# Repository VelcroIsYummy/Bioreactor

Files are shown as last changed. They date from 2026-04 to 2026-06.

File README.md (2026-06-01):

# Bioreactor?
This project is a expandable and usable bioreactor designed to allow **you** to grow bacteria, fungi, anything you can grow in a conventional bioreactor! Essencially this is a sterile volume, with ports or holes for instumentation (thermocouples, pH sensors, ect.) with software for controlling and managing the systems within. This bioreactor is unique (compared to other options at this price) by being very open and easy to build (some are open source, however they typically don't have great instructions on how to build your own.) Being very easily expandable, for example, extra slots are included if you want more motors, and it's easy to just add them (all design files are included.) And finally, being much larger than most other options (500mL.)

# Why?
Decentralized science is one of the most pivotal steps toward our future, wether it's finding a cure for an obscure disease (very unlikely), or providing resources to those who need it, decentralized science is the solution. Our project enables this, helping fuel a better future for us all. Perhaps one day someone will use it for something like producing insulin in areas that have limited outside access. The reason why I personally needed this is simple: I have a science fair that involves the growth of bacteria.

# Features
This bioreactor is a pretty full-fledged bioreaction system, it can grow almost any organism (that you could with a insustrial bioreactor), has dosing systems, optical density measurments, temprature control and a online, accessible UI. The only thing that this bioreactor can't handle is significant pressure differentials, as it's just not meant for that.

## BOM
| Name | Purpose | Quantity | Total Cost (USD) | Link | Distributor |
| --- | --- | --- | --- | --- | --- |
| Perfboard | It is used to connect everything together. | 1 | 8.00 | https://www.amazon.ca/Protoboard-Solderable-Breadboard-Electronics-Projects/dp/B0B9F2DNXD/ | Amazon |
| Schottky Diodes (Pack of 10) | The Schottky diodes are so that the MOSFET doesn't burn out due to back EMF. | 1 | 3.41 | https://www.aliexpress.com/item/1005007566611868.html | Aliexpress  |
| 500mL Media Storage Bottle | It shall be used to contain the media in which the biological processes are happening. | 1 | 30.00 | https://stonylab.com/products/250ml-wide-mouth-media-storage-bottle?variant=47202194620674 | StonyLab |
| CoPA filament | It is to print some parts that will either be exposed to warm temperatures and that will be contacting the media (for sterilization reasons.) And yes you only need a few hundred grams but this is the smallest size I could find. | 1 | 43.70 | https://www.amazon.ca/gp/product/B09MTC51RH/ | Amazon |
| 20x20x6mm fan | This fan is used to pass air through the PTFE filter, a high airflow isn't required for my perposes but you may need it. | 2 | 3.72 | https://www.aliexpress.com/item/1005009082132202.html | Aliexpress  |
| S8050 | It is used to switch the MOSFET on and off, | 1, Pack of 20 | 1.40 | https://www.aliexpress.com/item/1005008583538092.html | Aliexpress  |
| IRFZ44N | The MOSFET is used both for motor control, and for the control of the heater. | 1, Pack of 10 | 2.42 | https://www.aliexpress.com/item/1005007580466441.html | Aliexpress  |
| Thermal Paste | The thermal paste is so that the heater pad and the media container can have proper conduction, as otherwise heat transfer would be poor. | 1 | 8.74 | https://www.amazon.ca/Thermal-Grizzly-Kryonaut-Grease-Paste/dp/B011F7W3LU/ | Amazon |
| MAX6675 | It is so that I may use the thermocouple in coordination with the Arduino. | 1 | 6.50 | https://www.amazon.ca/MAX6675-Thermocouple-Temperature-Sensor-Module/dp/B07YC25RFW/ | Amazon |
| Type K thermometer | It is used for PID control and data collection. | 1 | 8.74 | https://www.amazon.ca/MECCANIXITY-Surface-Thermocouple-Handheld-Temperature/dp/B0CCSKDCW3/ | Amazon |
| Geared Motor | It is used in order to stir the media, allowing equal dispersion of materials and organisms. | 1 | 15.60 | https://www.aliexpress.com/item/1005010720335071.html | Aliexpress  |
| Silicone Heating Pad 12V/40W | It is used for heating and maintaining the temperature of the media. | 1 | 10.00 | https://www.aliexpress.com/item/1005005338245057.html | Aliexpress  |
| 12V/15A Power Supply | I shall use this PSU for powering the Bioreactor's systems. | 1 | 19.67 | https://www.aliexpress.com/item/1005011601037869.html | Aliexpress  |
| Arduino R4 WiFi | The Arduino WiFi is used for the control of biological processes (pH control, temperature control, ect.) and for communications through MQTT and a python API. | 1 | 27.50 | https://store-usa.arduino.cc/collections/uno/products/uno-r4-wifi | Arduino |
| 5mm LED | The light emitting diodes are used to pass light through ~1cm of media and calculate the OD600. | 1, Pack of 100 (smallest I could find) | 6.50 | https://www.amazon.ca/gp/product/B09BPQWV2W/ | Amazon |
| Adafruit TSL2591 | Used to measure the intensity of light on the other side of the media, thus allowing the calculation of OD600. | 1 | 6.95 | https://www.digikey.ca/fr/products/detail/adafruit-industries-llc/1980/4990786 | DigiKey |
| 25mm PTFE Filters, Hydrophillic | Used to prevent contaminants like bacteria and water from getting into the reactor vessel | 1, Pack of 50 (minimum size) | 12.90 | https://www.amazon.ca/Deschem-Hydrophilized-Membrane-Filter-Polytetrafluoroethylene/dp/B07TC2RQYN | Amazon |
| 3m 18mm OD 14mm ID Sillicone Tube | Used to move air through a filter into the bioreactor, allowing the growth of aerobic bacteria. | 1 | 6.50 | https://amazon.ca/silicone-flexible-rubber-tubing-transparent/dp/b08hjgwkx3/?th=1 | Amazon |
| 5.4mm Luer fittings female | Used to allow a sterile connection that can move fluids, very useful for doising and extraction. | 1 | 4.90 | https://www.amazon.ca/Hynec-Polypropylene-Female-Luer-Connector/dp/B0F1ZX2S71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 | Amazon |
| Luer tube | Used to move fluids in a sterile way between the reagent tubes and the vessel. | 4 | 7.20 | https://www.aliexpress.com/item/1005005528071293.html | Aliexpress |

(The reason the prices are in USD is because origonally this project was for Stasis, however I migrated before I really started doing most of the coding and design.) Another note, I'm not requesting funding for all of these since I have a lot of the parts.

# Usage
The usage of this bioreactor is pretty simple, after assembly, connect it to the internet (you can put in your WiFi password by just adding it to the "secrets.h" file.) After this, just turn on the PSU, and connect to it on the internet. The process by which you connect everything together, and set up the web UI is detailed in the instructions.

# Requirements/Libraries
For this project to work you will need to download the following libraries:

## Arduino

- PID (https://github.com/br3ttb/Arduino-PID-Library/tree/master)
- MAX6675 (https://github.com/RobTillaart/MAX6675)
- functional (included with Arduino IDE)
- WiFiS3 (included with Arduino IDE)
- ArduinoMqttClient (https://github.com/arduino-libraries/ArduinoMqttClient)
- RTC (https://github.com/cvmanjoo/RTC)
- Adafruit_Sensor (https://github.com/adafruit/adafruit_sensor)
- Adafruit_TSL2591 (https://github.com/adafruit/Adafruit_TSL2591_Library/)
- HttpClient (https://github.com/amcewen/HttpClient)
- Wire (Included with Arduino IDE)

## Python
- FastAPI (https://github.com/fastapi/fastapi)

# Disclamer
While I made most of this project myself, I obviously didn't create certain things like the libraries. I also used resources like StackOverflow for this. Another thing to note, I did not create the original models for the ported caps and the headplate, I simply _**CANNOT**_ make threads for some reason.

## Refrences I Used
- Python Docs
- Javascript MDN Docs
- ElectroNoobs (https://electronoobs.com/)
- Examples (The files that are included with most libraries, showing how to use them)
- StackOverflow
- W3, for learning (I'm still new to this stuff)

# Schematic
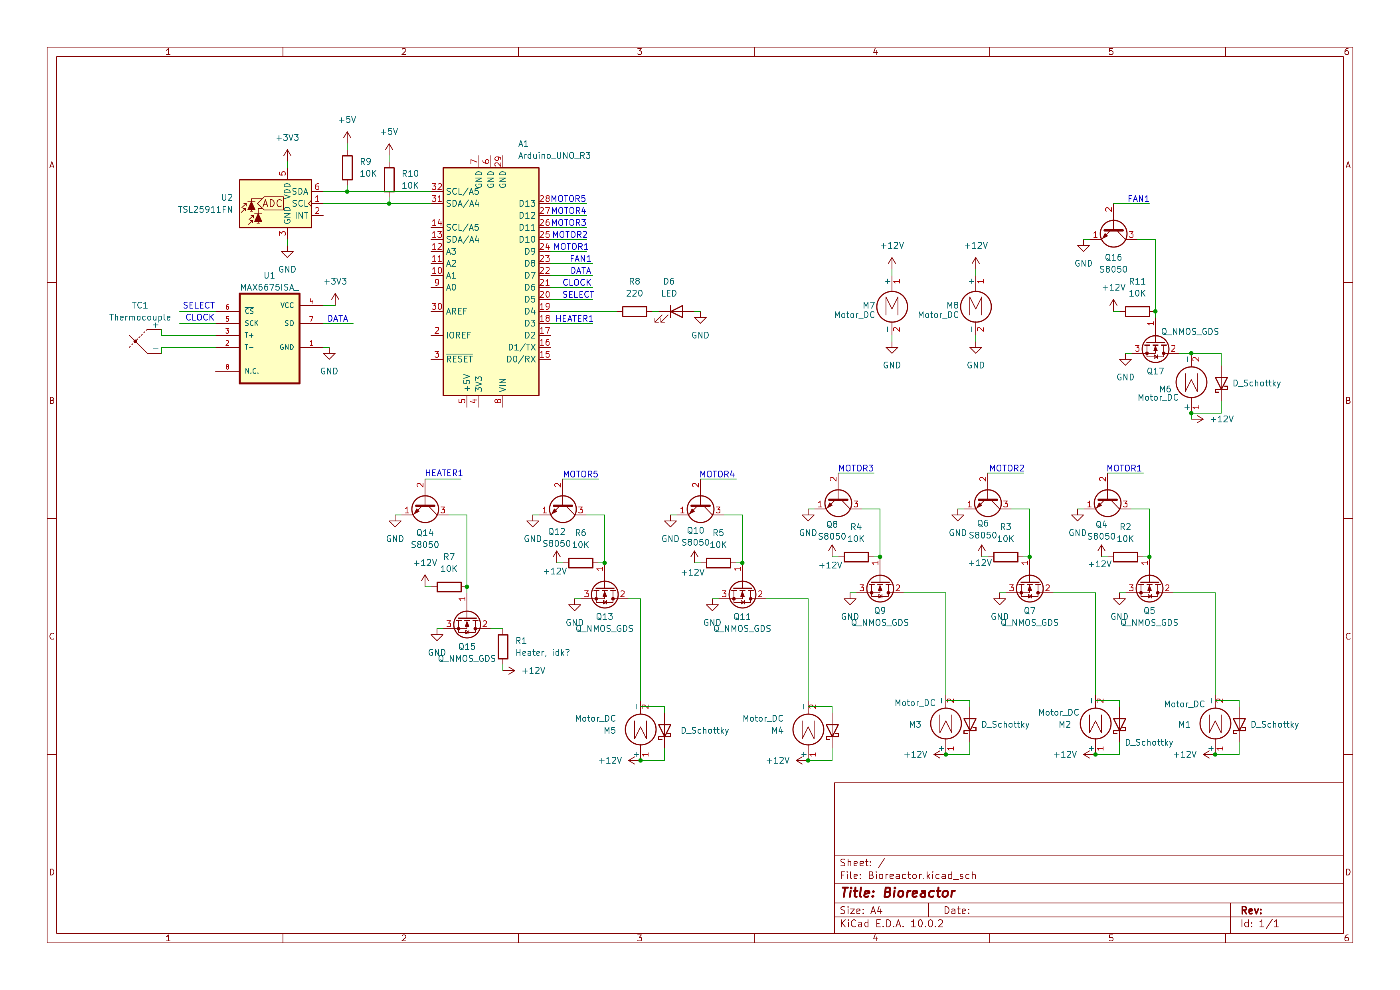
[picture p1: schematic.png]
Schematic


# Zine
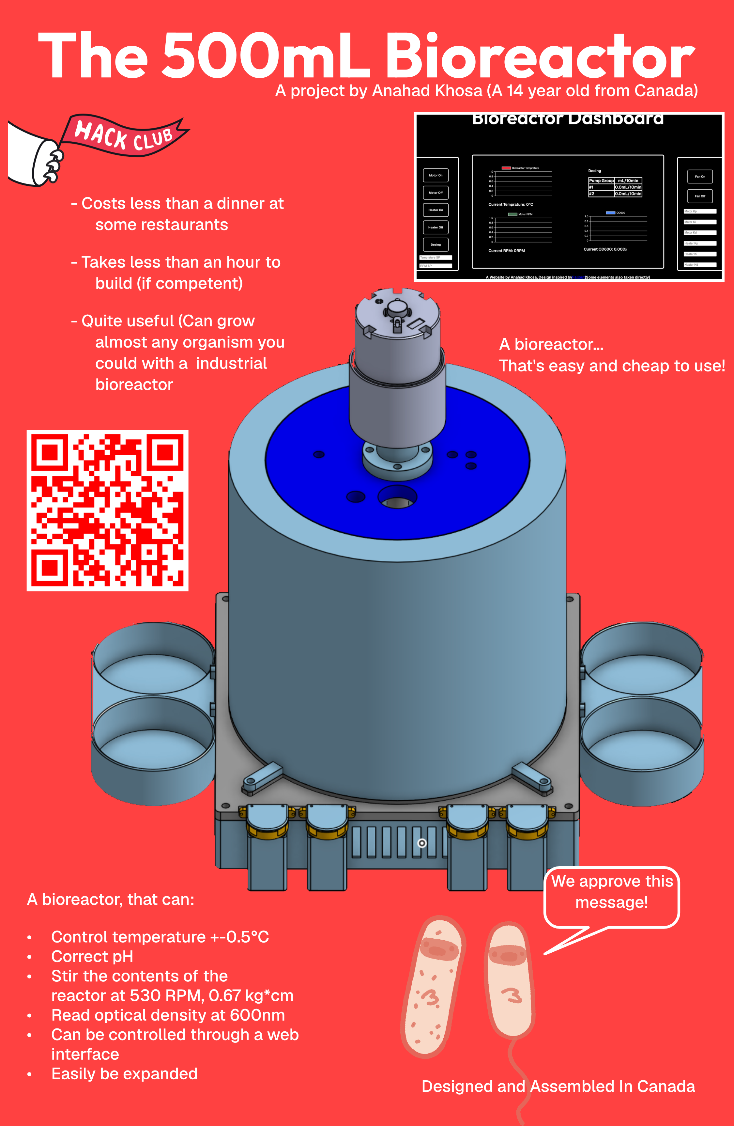
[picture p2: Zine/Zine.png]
Zine


# Onshape Links
Here are the onshape links if you want them
- For the Arduino Enclosure, the motor holder, reagent bottle holder and the assembly of everything put together https://cad.onshape.com/documents/7da2fef4892da00e546072ac/w/9fd6f0965d1d0b5f1b6a90d1/e/e24ce9c144e045758d9770eb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
- For the heater holder, the motor shaft, and motor holder https://cad.onshape.com/documents/63b4c3fef69abd726d6ab222/w/4431f9c62b980bae8326396e/e/164de285b85071f5c7627032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
- Reagent bottle cap with 2 ports https://cad.onshape.com/documents/1eed58fe4840c910f07571ab/w/ff7b350df8e7dc2f2e59ebc7/e/ee4f5e3626b7f9089b5a21a8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
- Headplate, used to mount sensors and the motor https://cad.onshape.com/documents/97e268ccdf9d28071c848c08/w/29b871e1c28c8c8f8ed3ce92/e/f98ecdd4111ee4c6ba3b3adb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

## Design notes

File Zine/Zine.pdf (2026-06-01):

# The 500mL Bioreactor

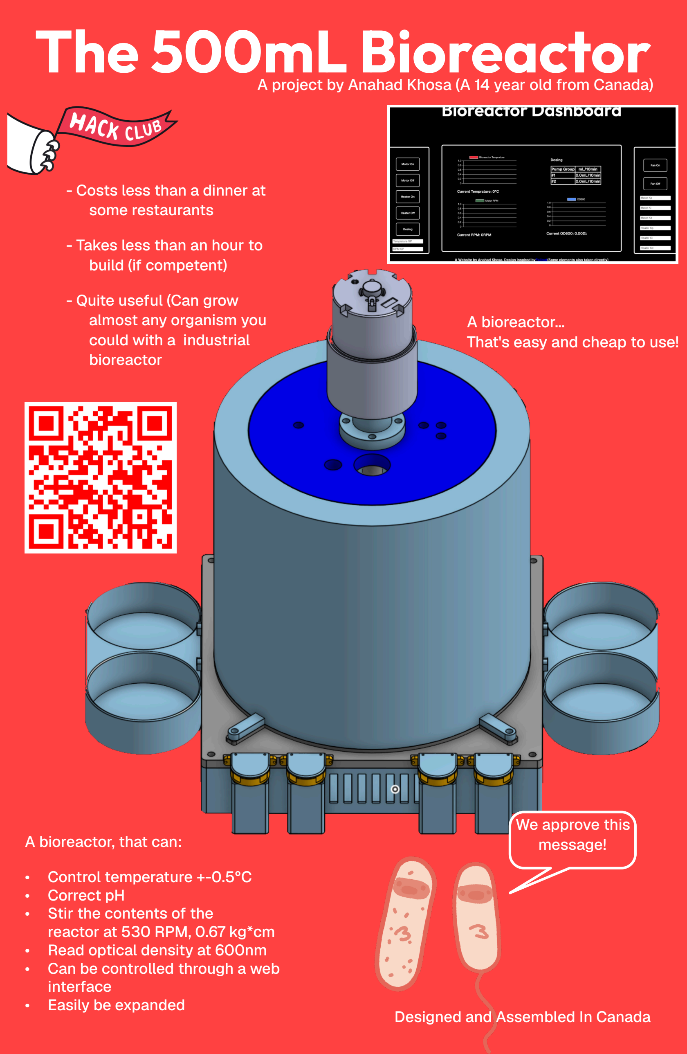
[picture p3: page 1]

A project by Anahad Khosa (A 14 year old from Canada)

A bioreactor...
That's easy and cheap to use!

A bioreactor, that can:

- Control temperature +-0.5°C
- Correct pH
- Stir the contents of the
reactor at 530 RPM, 0.67 kg*cm
- Read optical density at 600nm
- Can be controlled through a web interface
- Easily be expanded
- Costs less than a dinner at some restaurants
- Takes less than an hour to build (if competent)
- Quite useful (Can grow
almost any organism you
could with a industrial
bioreactor

Designed and Assembled In Canada

We approve this
message!

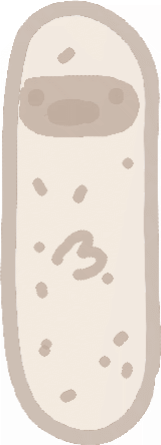
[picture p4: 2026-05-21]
src/Bioreactor GUI/Stew.png

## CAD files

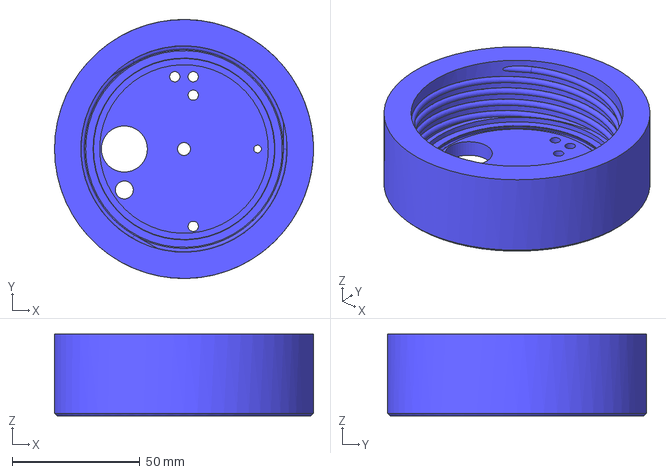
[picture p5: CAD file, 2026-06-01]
CAD/Headplate.step
101.4 x 101.4 x 32.0 mm

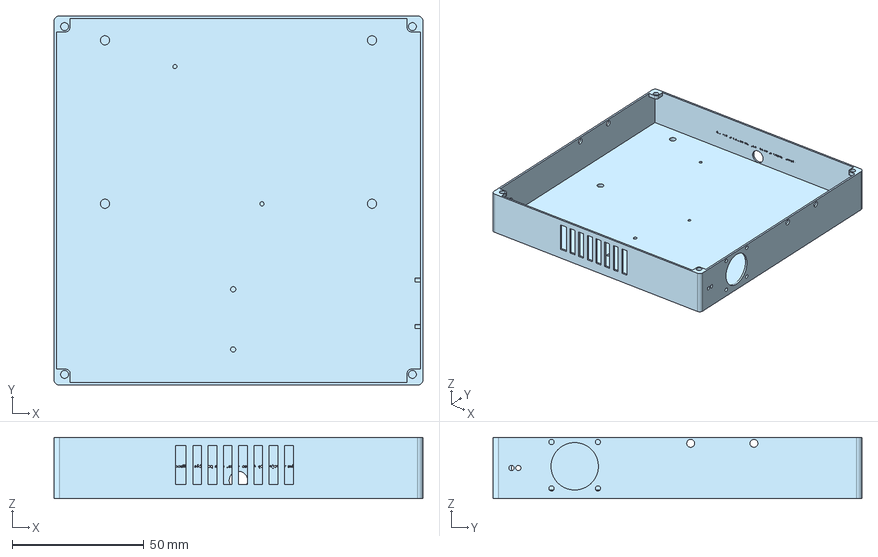
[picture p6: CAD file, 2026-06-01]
CAD/Arduino Enclosure.step
140.0 x 140.0 x 23.3 mm

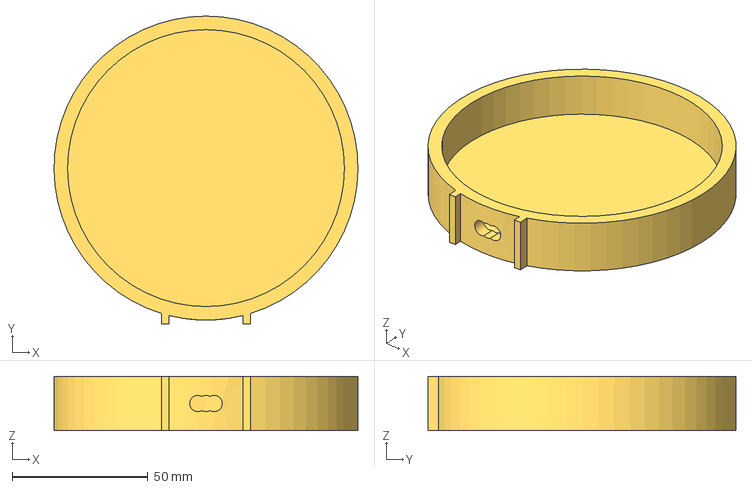
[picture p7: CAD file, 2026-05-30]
CAD/Heater Base.step
112.0 x 113.4 x 20.0 mm

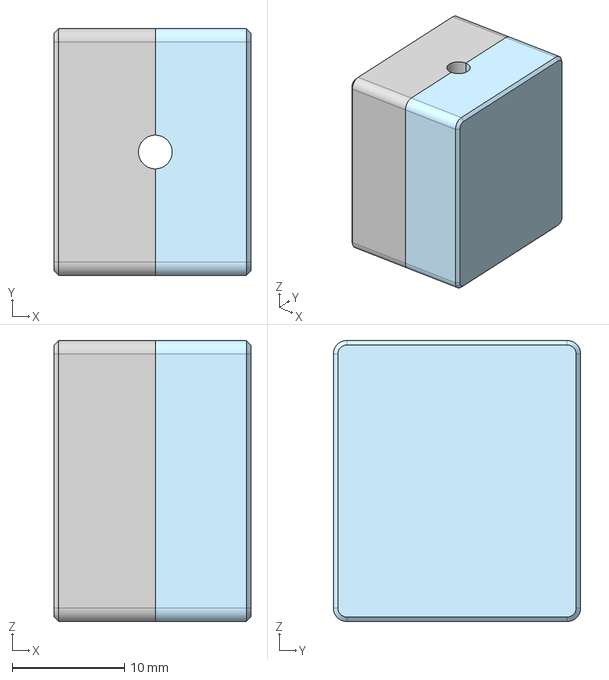
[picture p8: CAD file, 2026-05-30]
CAD/OD600 Module.step
17.5 x 22.0 x 25.0 mm

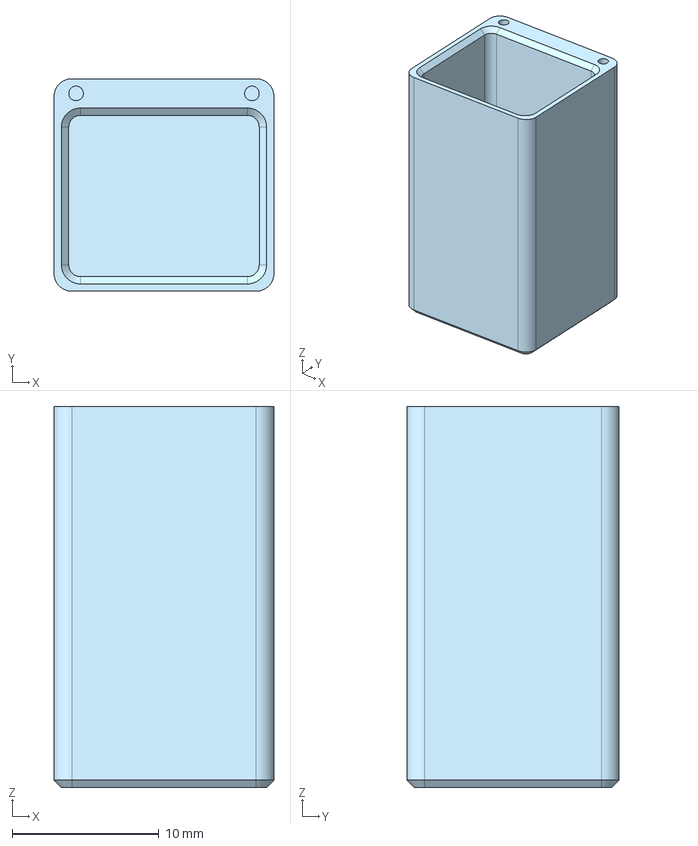
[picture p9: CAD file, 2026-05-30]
CAD/Dosing Motor Holder.step
15.0 x 14.5 x 26.0 mm

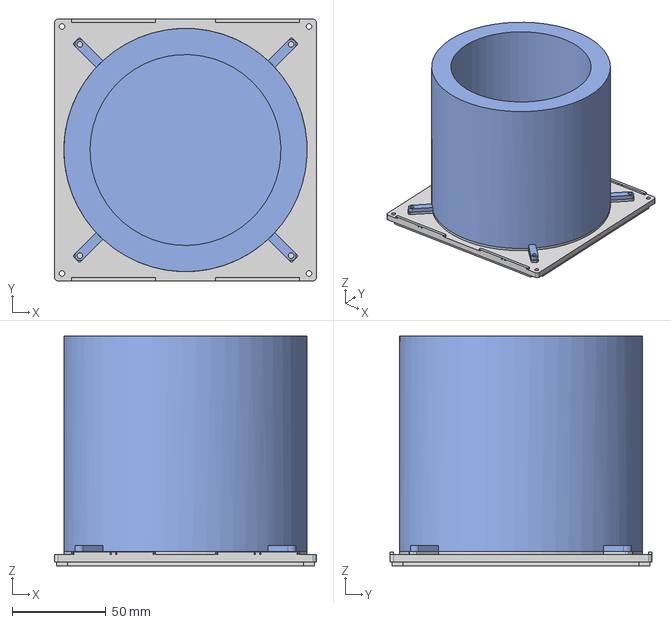
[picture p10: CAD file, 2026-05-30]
CAD/Arduino Enclosure Lid.step
140.0 x 140.0 x 122.8 mm

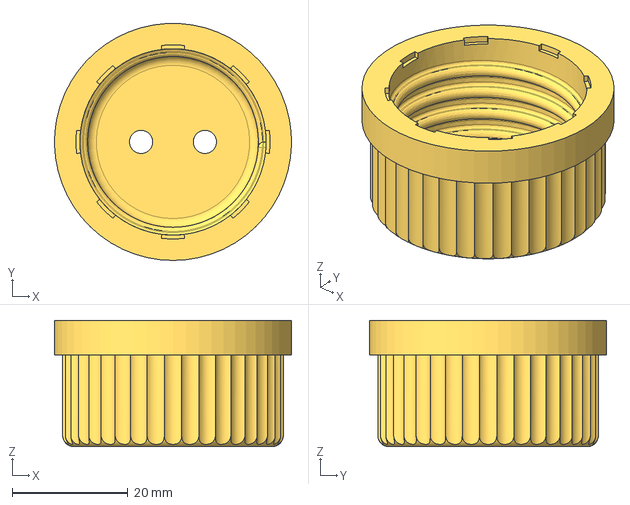
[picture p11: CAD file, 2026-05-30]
CAD/GL 32 Ported Cap.step
40.9 x 40.9 x 21.8 mm

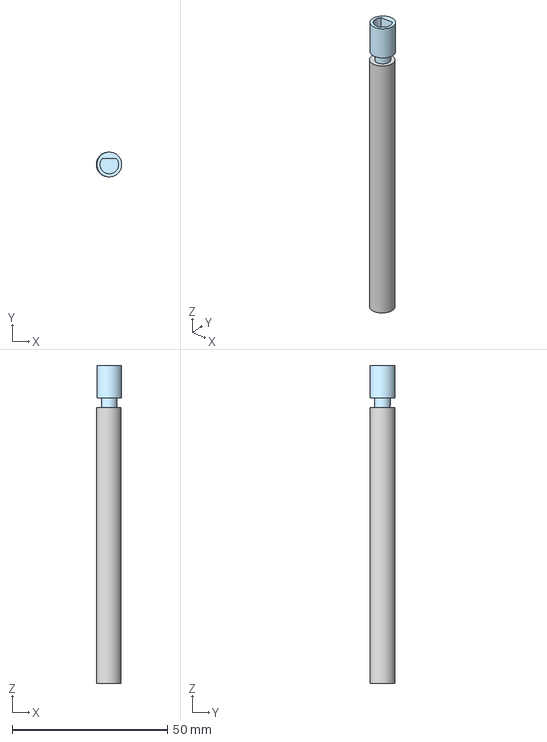
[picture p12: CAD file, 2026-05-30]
CAD/Labyrinth Seal.step
8.21 x 8.00 x 102.5 mm

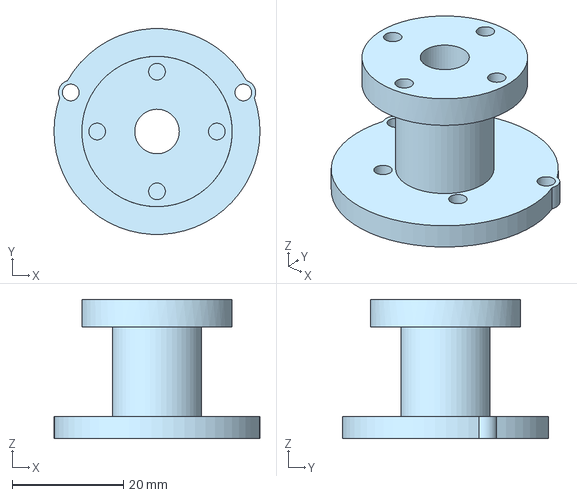
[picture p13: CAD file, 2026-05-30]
CAD/Motor Mount.step
37.0 x 36.9 x 25.0 mm

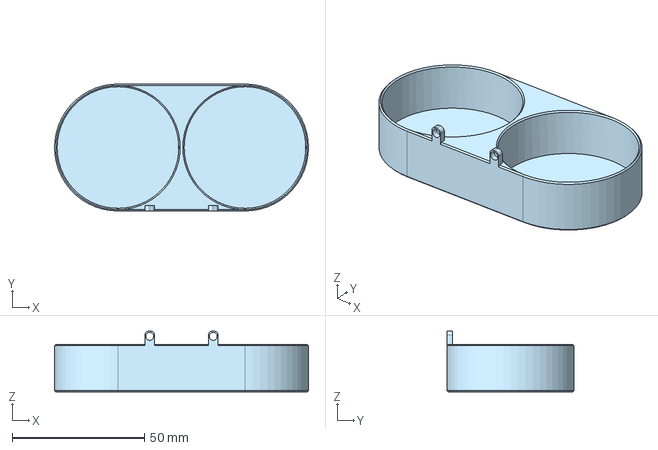
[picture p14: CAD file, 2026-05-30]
CAD/Arduino Enclosure Reagent Bottle Holder.step
96.0 x 48.0 x 23.0 mm

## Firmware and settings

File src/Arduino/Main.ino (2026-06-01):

#include <PID_v1.h>
#include "MAX6675.h"
#include <functional>
#include "WiFiS3.h"
#include "secrets.h"
#include <ArduinoMqttClient.h>
#include "RTC.h"
#include <Wire.h>
#include <Adafruit_Sensor.h>
#include "Adafruit_TSL2591.h"
#include <HttpClient.h>

using namespace std;

long dosesGiven = 0; float motor1DisplacementAmount = 0; float motor2DisplacementAmount = 0;
bool fanOn = false; const int fanPin = 8;
float motor3DisplacementAmount = 0; int timeToDosing = 600;
const int perlestaticMotor1Pin = 10; const int perlestaticMotor2Pin = 11; 
const int perlestaticMotor3Pin = 12; const int perlestaticMotor4Pin = 13;
int dosingTimer = 0; int msPerMl = 1000; float int motorFluidCaptureDelay = 100;
const int dataPin = 7; const int clockPin = 6; const int selectPin = 5;
const int heaterPin = 3; const int motorPin = 9;
const int ledPin = 4;
int telemetryTimeSinceLastMessage = 0;
const char brokerUrl[] = "test.mosquitto.org"; const int brokerPort = 1883;
const int encoderInputPin = 2; const int encoderRevoultionsPerRotationOfMotorShaft = 11;
volatile int encoderPulses = 0;
double heaterKp = 0; double heaterKi = 0; double heaterKd = 0;
double rpmKp = 0; double rpmKi = 0; double rpmKd = 0;
bool on = false; bool motorOn = false; bool heaterOn = false;
double heaterSetpoint = 0; double heaterOutput = 0; double rpmSetpoint = 0; 
double rpmOutput = 0;
double thermocoupleTemp = 0; double motorRpm = 0;
const int maxRpm = 530; const int maxTemp = 60;

MAX6675 thermoCouple(selectPin, dataPin, clockPin);
uint32_t start, stop;

PID heaterPID(&thermocoupleTemp, &heaterOutput, &heaterSetpoint, 
  heaterKp, heaterKi, heaterKd, DIRECT);
PID rpmPID(&motorRpm, &rpmOutput, &rpmSetpoint, rpmKp, rpmKi, rpmKd, DIRECT);
void setup() {
  Serial.begin(9600);
  Wire.begin();
  WiFi.setTimeout(0);
  WiFi.begin(SSID, PASS);
  while (WiFi.status() != WL_CONNECTED) {}
  Adafruit_TSL2591 od600LuminositySensor = Adafruit_TSL2591(2591);
  od600LuminositySensor.setGain(TSL2591_GAIN_LOW);
  od600LuminositySensor.setTiming(TSL2591_INTEGATIONTIME_100MS); // no idea if that's good, might change
  WiFiClient client;
  MqttClient mqttClient(client);
  HttpClient http(client);
  mqttClient.connect(brokerUrl, brokerPort);
  mqttClient.onMessage(reciveMqttMessage);
  mqttClient.subscribe("BioreactorGui/onOffButton");
  mqttClient.subscribe("BioreactorGui/heaterOnOffButton");
  mqttClient.subscribe("BioreactorGui/fanOnOffButton");
  mqttClient.subscribe("BioreactorGui/motorOnOffButton");
  mqttClient.subscribe("BioreactorGui/heaterSetpoint");
  mqttClient.subscribe("BioreactorGui/heaterKp");
  mqttClient.subscribe("BioreactorGui/heaterKi");
  mqttClient.subscribe("BioreactorGui/heaterKd");
  mqttClient.subscribe("BioreactorGui/rpmSetpoint");
  mqttClient.subscribe("BioreactorGui/rpmKp");
  mqttClient.subscribe("BioreactorGui/rpmKi");
  mqttClient.subscribe("BioreactorGui/rpmKd");
  mqttClient.subscribe("BioreactorGui/dosingSchedulingM1");
  mqttClient.subscribe("BioreactorGui/dosingSchedulingM2");
  mqttClient.subscribe("BioreactorGui/dosingSchedulingM3");
  pinMode(encoderInputPin, INPUT_PULLUP);
  attachInterrupt(digitalPinToInterrupt(encoderInputPin), incrementEncoderPulse, RISING);
  pinMode(heaterPin,OUTPUT);
  pinMode(motorPin, OUTPUT);
  pinMode(perlestaticMotor1Pin, OUTPUT);
  pinMode(perlestaticMotor2Pin, OUTPUT);
  pinMode(perlestaticMotor3Pin, OUTPUT);
  pinMode(perlestaticMotor4Pin, OUTPUT);
  pinMode(ledPin, OUTPUT);
  SPI.begin();
  thermoCouple.begin();
  heaterPID.SetMode(AUTOMATIC);
  rpmPID.SetMode(AUTOMATIC);
  RTC.begin();
  RTCTime rtc(30, Month::JUNE, 1970, 00, 00, 00, DayOfWeek::TUESDAY, 
    SaveLight::SAVING_TIME_ACTIVE);
  RTC.setTime(rtc);
  RTC.setPeriodicCallback(rtcIncrement, Period::ONCE_EVERY_2_SEC);
  RTC.setPeriodicCallback(sendTelemetry, Period::ONCE_EVERY_2_SEC);
}

void loop() {
  delay(950);
  if (WiFi.status() != WL_CONNECTED) {
    if (WiFi.begin(SSID, PASS) != WL_CONNECTED) {
      // something to notify about lack of connection?
    }
  }
  if (on == true) {
    onLoop();
  }
}

double od600Measurement() {
  digitalWrite(perlestaticMotor4Pin, HIGH);
  delay(motorFluidCaptureDelay);
  digitalWrite(perlestaticMotor4Pin, LOW);
  digitalWrite(ledPin, HIGH);
  uint16_t luminosityMeasurement = od600LuminositySensor.getLuminosity(TSL2591_VISIBLE);
  digitalWrite(ledPin, LOW);
  double od600 = -log10(luminosityMeasurement/2000); // assuming exactly 1cm of media.
  return od600;
}

double checkThermocouple() {
  start = micros();
  int status = thermoCouple.read();
  stop = micros();
  double thermocoupleTemp = thermoCouple.getCelsius();
  return thermocoupleTemp;
}

void onLoop() {
  mqttClient.poll();
  if (heaterOn == true) {
    onHeater();
  }
  if (heaterOn != true) {
    digitalWrite(heaterPin, HIGH);
  }
  if (motorOn == true) {
    onMotor();
  }
  if (motorOn != true) {
    digitalWrite(motorPin, 255);
  }
  if (fanOn == true) {
    onFan();
  }
  if (fanOn != true) {
    digitalWrite(fanPin, 255);
  }
  if (dosingTimer == timeToDosing) {
    motorCallback();
  }
}

void onHeater() {
  thermocoupleTemp = checkThermocouple();
  heaterPID.Compute();
  analogWrite(heaterPin, 255 - heaterOutput);
}

void onOd600() {
  od600Measurement();
}

void onFan() {
  digitalWrite(fanPin, HIGH);
}

void onMotor() {
  motorRpm = checkEncoder();
  rpmPID.Compute();
  analogWrite(motorPin, 255 - rpmOutput);
}

double checkEncoder() {
  double motorRpm = encoderPulses/encoderRevoultionsPerRotationOfMotorShaft * 60;
  encoderPulses = 0;
  return motorRpm;
}

void incrementEncoderPulse() {
  encoderPulses++;
}

void reciveMqttMessage(int messageSize) {
  String messageTopic = mqttClient.messageTopic();
  if (messageTopic == "BioreactorGui/onOffButton") {
    if ("true" == String(mqttClient.read())) {
      on = true;
    }
    else {
      on = false;
    }
  }
  if (messageTopic == "BioreactorGui/heaterOnOffButton") {
    if ("true" == String(mqttClient.read())) {
      heaterOn = true;
    }
    else {
      heaterOn = false;
    }
  if (messageTopic == "BioreactorGui/motorOnOffButton") {
    if ("true" == String(mqttClient.read())) {
      heaterOn = true;
    }
    else {
      heaterOn = false;
    }
  }
  if (messageTopic == "BioreactorGui/fanOnOffButton") {
    if ("true" == String(mqttClient.read())) {
      fanOn = true;
    }
    else {
      fanOn = false;
    }
  }
  if (messageTopic == "BioreactorGui/heaterSetpoint") {
    double payload = String(mqttClient.read()).toDouble();
    if (payload <= maxTemp) {
    heaterSetpoint = payload;
    }
  }
  if (messageTopic == "BioreactorGui/heaterKp") {
    double payload = String(mqttClient.read()).toDouble();
    heaterKp = payload;
  }
  if (messageTopic == "BioreactorGui/heaterKi") {
    double payload = String(mqttClient.read()).toDouble();
    heaterKi = payload;
  }
  if (messageTopic == "BioreactorGui/heaterKd") {
    double payload = String(mqttClient.read()).toDouble();
    heaterKd = payload;
  }
  if (messageTopic == "BioreactorGui/rpmSetpoint") {
    double payload = String(mqttClient.read()).toDouble();
    if (payload <= maxRpm) {
      rpmSetpoint = payload;
    }
  }
  if (messageTopic == "BioreactorGui/rpmKp") {
    payload = String(mqttClient.read()).toDouble();
    double rpmKp = payload;
  }
  if (messageTopic == "BioreactorGui/rpmKi") {
    double payload = String(mqttClient.read()).toDouble();
    double rpmKi = payload;
  }
  if (messageTopic == "BioreactorGui/rpmKd") {
    double payload = String(mqttClient.read()).toDouble();
    double rpmKd = payload;
  }
  if (messageTopic == "Bioreactor/dosingSchedulingM1") {
    float payload = String(mqttClient.read()).toDouble();
    double motor1DisplacementAmount = payload;
  }
    if (messageTopic == "Bioreactor/dosingSchedulingM2") {
    double payload = String(mqttClient.read()).toDouble();
    motor2DisplacementAmount = payload;
  }
    if (messageTopic == "Bioreactor/dosingSchedulingM3") {
    double payload = String(mqttClient.read()).toDouble();
    motor3DisplacementAmount = payload;
  }
}}

void rtcIncrement() {
  dosingTimer + 2;
}

void motorCallback() {
  dosingTimer = 0;
  if (motor1DisplacementAmount > 0) {
    int motor1RunTime = motor1DisplacementAmount*1000/msPerMl;
    digitalWrite(perlestaticMotor1Pin, HIGH);
    digitalWrite(perlestaticMotor4Pin, HIGH);
    delay(motor1RunTime);
    digitalWrite(perlestaticMotor1Pin, LOW);
    digitalWrite(perlestaticMotor4Pin, LOW);
  }
  if (motor2DisplacementAmount > 0) {
    int motor2RunTime = motor2DisplacementAmount*1000/msPerMl;
    digitalWrite(perlestaticMotor2Pin, HIGH);
    digitalWrite(perlestaticMotor4Pin, HIGH);
    delay(motor2RunTime);
    digitalWrite(perlestaticMotor2Pin, LOW);
    digitalWrite(perlestaticMotor4Pin, LOW);
  }
  if (motor3DisplacementAmount > 0) {
    int motor3RunTime = motor3DisplacementAmount*1000/msPerMl;
    digitalWrite(perlestaticMotor3Pin, HIGH);
    digitalWrite(perlestaticMotor4Pin, HIGH);
    delay(motor3RunTime);
    digitalWrite(perlestaticMotor3Pin, LOW);
    digitalWrite(perlestaticMotor4Pin, LOW);
  }
}

void sendTelemetry() {
  if (telemetryTimeSinceLastMessage == 10) {
  http.begin(NESTIP, DATABASEPORT);
  http.addHeader("Content-Type", "application/json"")
  http.POST(std::format(
    "{\"temperature\":\"{}\",\"pH\":\"{}\",\"rpm\":\"{}\",\"od600\":\"{}\",\"key\":\"{}\"}",
    thermocoupleTemp, pH, motorRpm, od600Measurement, APIKEY));
  telemetryTimeSinceLastMessage = 0;
}
  else {
    telemetryTimeSinceLastMessage + 2;
  }
}

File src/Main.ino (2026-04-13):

#include <Wire.h>

/* Now I hate annotating my code, but since wilson will be working on this
and the judges will be looking at it. I guess I can swallow my pride and just
do it for once. */



// This is for a mosfet, according to a yt video i found the easiest way to
// control a mosfet w/ arduino is to use a BJT npn also, this needs a pullup
int PWM_pin = 3;

// I choose a class because it's easy, and 
// I might have to make multiple PID loops
class PIDControl { 
  public:
    int kp; // gains for p i and d, gotta tune them
    int ki; // also these are bassically divided by 100 later in the code
    int kd; // maybe I should lower the jank?
    // PID temp control vars
    float setpoint; // Set points are our target temprature
    float val; // Our current value, eg. temp, pH, DO
    float error; // current error in temp
    float preverror = 0 // previous error, required for derivative
    float elapsedTime, Time, timePrev; // required for intergral
    std::function<float()> readSensor; // Bassically does a function

    int start (kp, ki, kd, setpoint, std::function<float()> sensorFn):
    kp(kp), ki(ki), kd(kd), setpoint(setpoint), readSensor(sensorFn) {
      val = readSensor(); // Pass in function
     //Next we calculate the error between the setpoint and the real value

      PID_error = set_temperature - temperature_read + 3;
      //Calculate the P value
      PID_p = 0.01*kp * PID_error;
      //Calculate the I value in a range on +-3
      PID_i = 0.01*PID_i + (ki * PID_error);
      //For derivative we need real time to calculate speed change rate
      timePrev = Time;                            
      Time = millis();                            
      elapsedTime = (Time - timePrev) / 1000; 
      //Now we can calculate the D value
      PID_d = 0.01*kd*((PID_error - previous_error)/elapsedTime);
      //Final total PID value is the sum of P + I + D
      PID_value = PID_p + PID_i + PID_d;
      preverror = error;

      constrain(PID_value, 0, 255); // stops errors cuz we can't have -pwm

  private:
    int PID_p = 0;    int PID_i = 0;    int PID_d = 0;
  
}





void setup() {
  pinMode(PWM_pin,OUTPUT);
  SetPinFrequencySafe(3, 928)
}




analogWrite(PWM_pin,255-PID_value);

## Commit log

2026-04-16 Added code to check thermistor temp.
2026-05-03 fixed the code, accidentally left example in.
    [Main.ino]
2026-05-05 Encoder
    must work on this
2026-05-05 Update dc_encoder.ino
    Added a comment to the ENCODEROUTPUT definition.
2026-05-05 Update comment for ENCODEROUTPUT definition
2026-05-05 Update comments in dc_encoder.ino
    Removed a comment about sleep deprivation and added a new comment about the encoder functionality.
2026-05-14 Added some thingies
    [Bioreactor v1.step]
2026-05-16 Deleted old encoder code and added gitnore to secrets.h
2026-05-30 Added a backend/database. Also reorganized and added OD600 measurement.
    [config.csv, database.csv]
2026-05-30 Added new CAD files. Updated README.
    [Arduino Enclosure Lid.step, Arduino Enclosure Reagent Bottle Holder.step, Arduino Enclosure.step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]
2026-05-30 Added database comms to website.
    [database.csv]
2026-05-31 Modified web interface
    [config.csv]
2026-05-31 Changed colours, and also added proper dosing
    [config.csv]
2026-06-01 Fixed errors and added support for a fan.
    [config.csv]
2026-06-01 Added README, added a way to update the config.csv. Updated CAD.
    [Arduino Enclosure.step, Bioreactor.kicad_sch, Headplate.step]
2026-06-01 Updated BOM in Markdown and added csv file.
    [BOM.csv]
2026-06-28 fixed BOM
    [BOM.csv]
2026-06-28 BOM fixed
    [BOM.csv]
